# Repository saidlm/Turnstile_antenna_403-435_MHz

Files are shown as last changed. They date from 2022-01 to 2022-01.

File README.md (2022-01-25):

# Turnstile antenna
The antenna was primary designed for weather balloon tracker station based. It means my first dessign is for 403Mhz (400Mhz - 406Mhz). The solution is based on well know priciples which can be easily found on the Internet. The next one is planned for satellite receiver on 435 Mhz band.

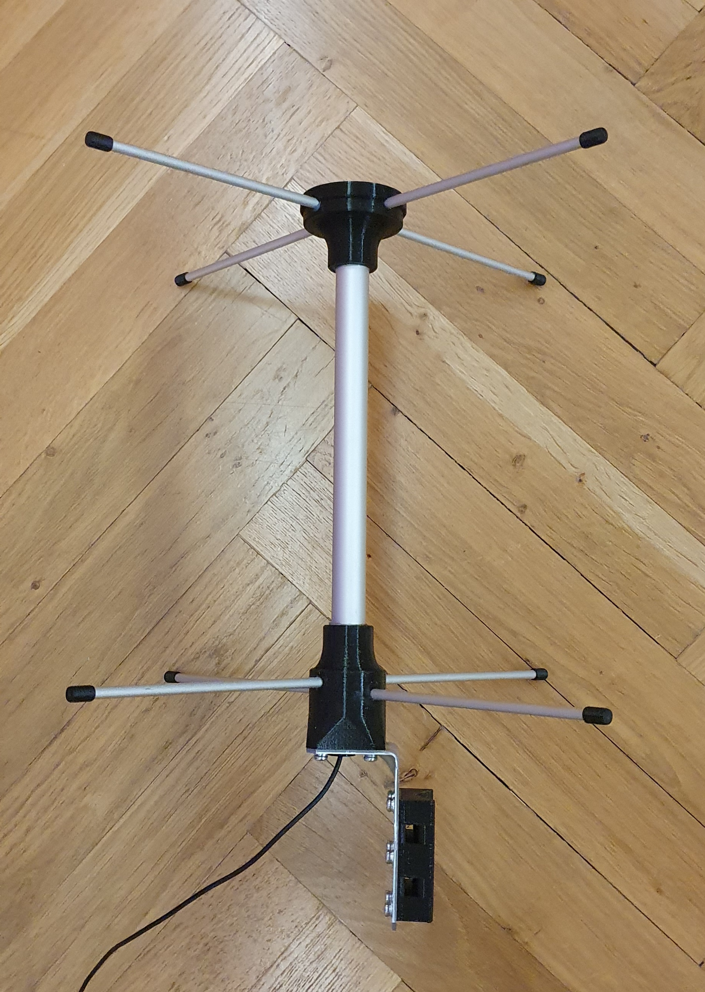
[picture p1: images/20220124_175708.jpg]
Turnstile Antenna


## Mechanical design
All platic parts have been printed from PET on Prusa MK2 3D printer. Four perimeters and 80% infill have been chousen. 
Measurements of ALU parts are summarized below. Dipole pipes are fixed with four screws M3x16mm. They are used for cables connection as well. Reflector pipes are fixed with one screw in the tube joint inside the bottom plastic part. To make whole antenna waterproof sillicone glue has been used.

## Turnstile antenna for 403Mhz

|Part|Description|
| :--- | :--- |
| **Dipole** |  4 pcs of ALU pipe 6mm x 164mm |
| **Reflector** |  2 pcs of ALU pipe 6mm x 354mm |
| **Pole** | 1 pc of ALU pipe 20mm x 262mm|

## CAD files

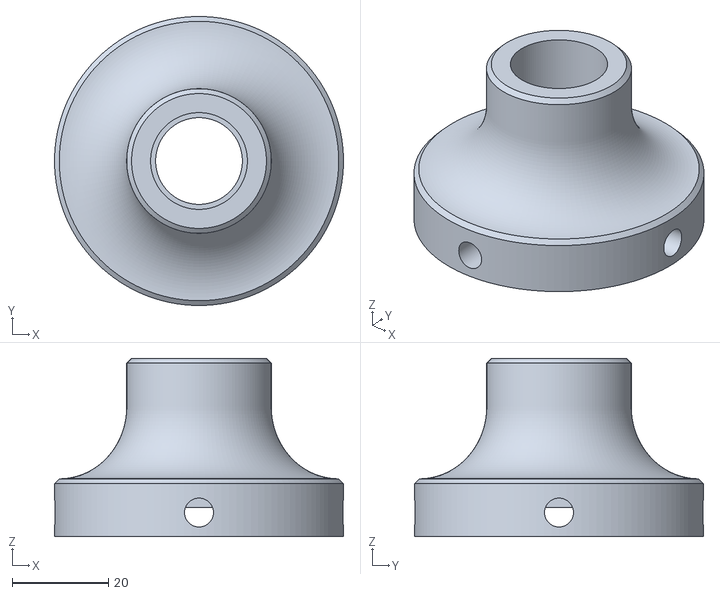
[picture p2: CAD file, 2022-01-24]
stl/top-0.1.stl
60.0 x 60.0 x 37.0

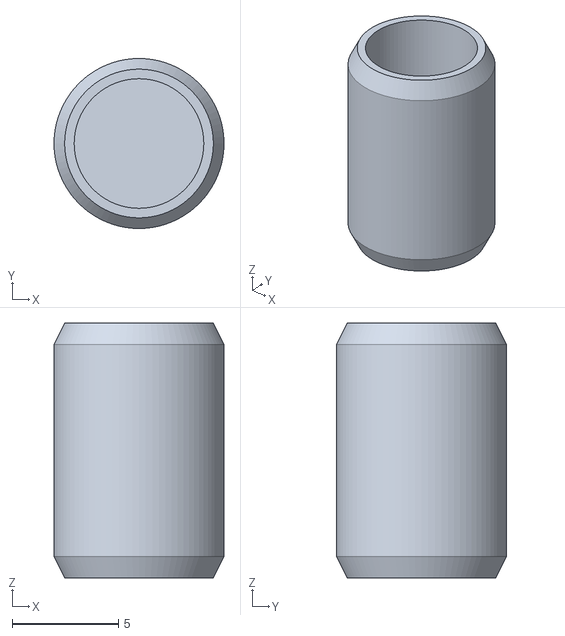
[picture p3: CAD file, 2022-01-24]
stl/end-cover-0.1.stl
8.00 x 8.00 x 12.0

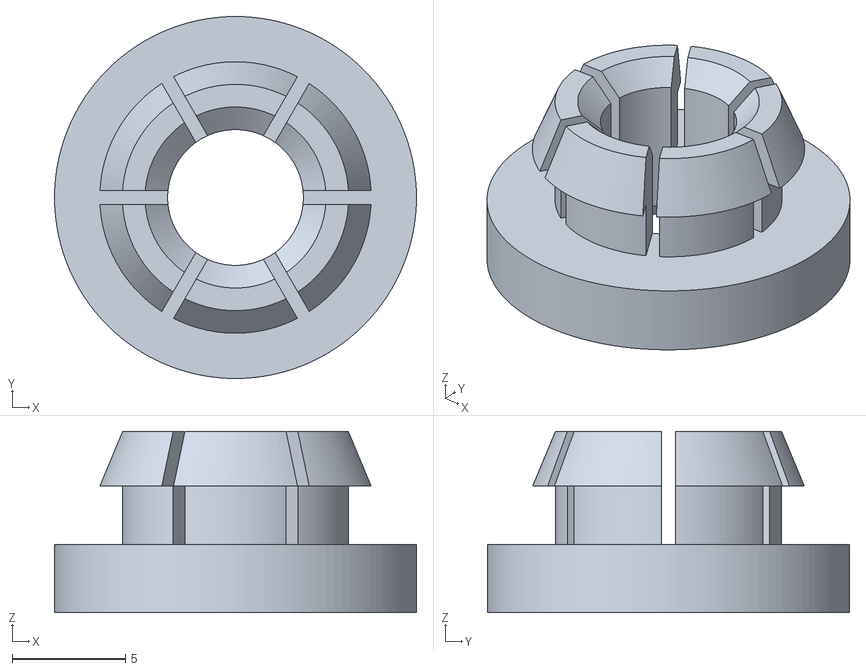
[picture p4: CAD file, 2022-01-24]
stl/cable-protection-0.1.stl
16.0 x 16.0 x 8.00

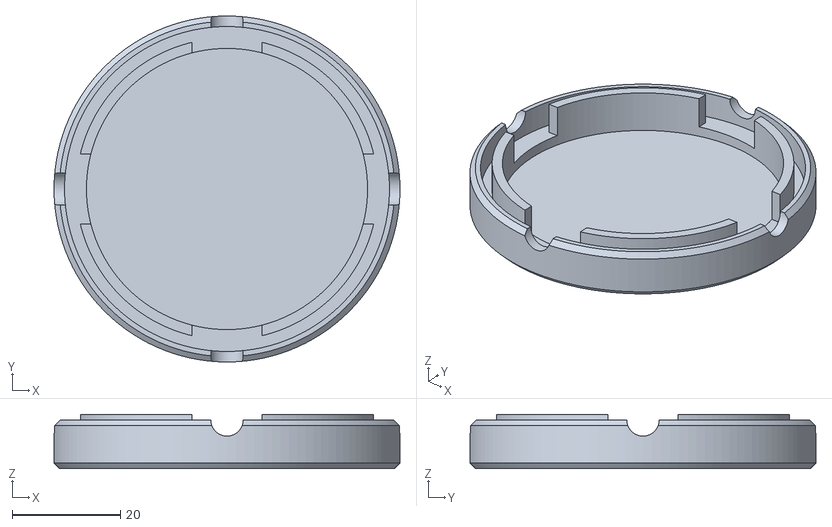
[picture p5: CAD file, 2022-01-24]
stl/top-cover-0.2.stl
64.0 x 64.0 x 10.0

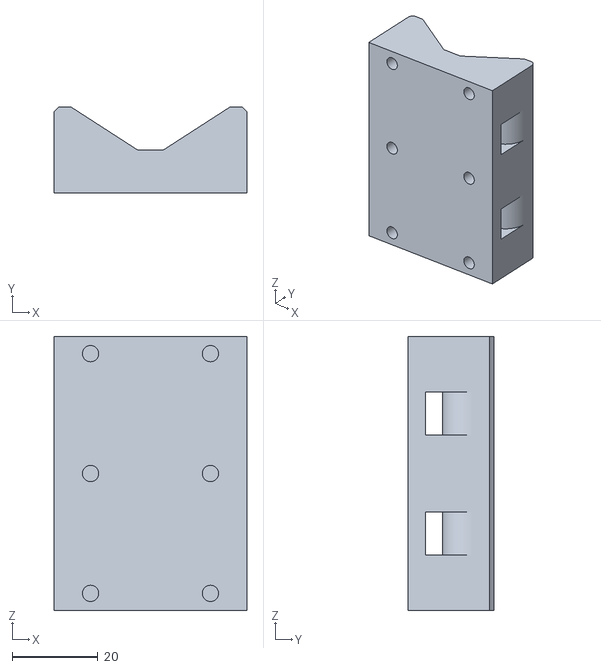
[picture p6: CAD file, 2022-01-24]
stl/holder-0.1.stl
45.0 x 20.0 x 64.0

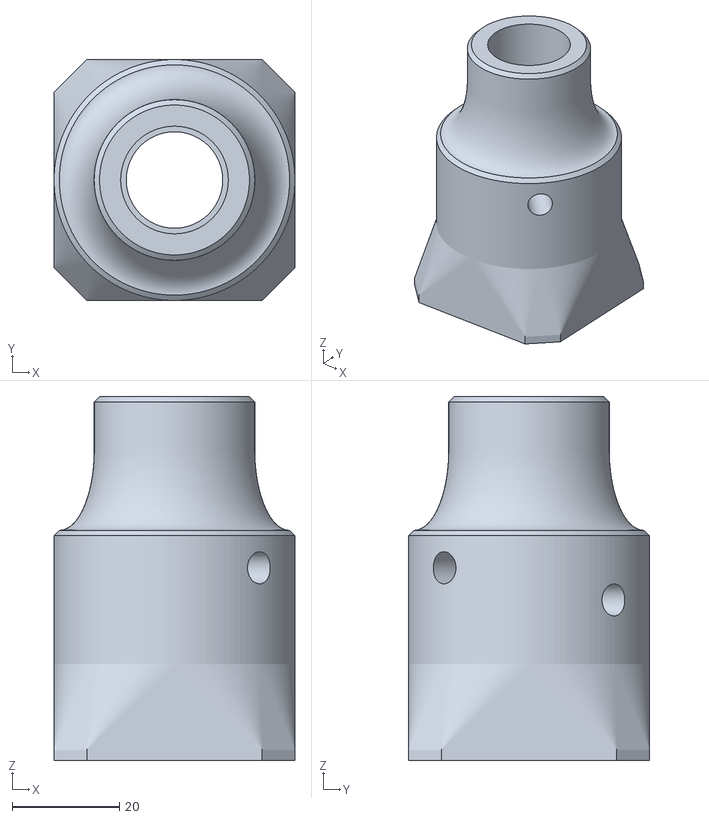
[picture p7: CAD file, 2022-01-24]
stl/bottom-0.2.stl
45.0 x 45.0 x 68.0

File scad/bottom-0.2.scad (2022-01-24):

$fn=120;
translate([0,0,25])difference() {
    union() {
        difference() {
            union() {
                cylinder(h=17, d=45);
                translate([0,0,17]) cylinder(h=1,d1=45,d2=43);
                cylinder(h=33, d=43);
                cylinder(h=42, d=30);
                translate([0,0,42]) cylinder(h=1,d1=30,d2=28);
            }
            translate([0,0,18])cylinder(h=25, d=20.1);
            cylinder(h=22, d=18);
            translate([0,0,33])
                rotate_extrude(convexity=10)
                translate([21.5, 0, 0])
                resize([13,30])circle(r=10);
        }  
    }
    translate([0,0,11])rotate([90,0,45])cylinder(h=60, d=6, center=true);
    translate([0,0,5])rotate([0,90,45])cylinder(h=60, d=6, center=true);
}

difference() {
    union() {
    cylinder(h=25, d=45);
    hull() {
        cylinder(h=18, d=45);
        translate([0,0,1])intersection() {
            cube([45,45,2], center=true);
            rotate([0,0,45])cube([55,55,2], center=true);
        }
    }
}
    cylinder(h=25, d1=25, d2=18);
    translate([14,14,0]) cylinder(h=15, d=3.7);
    translate([-14,14,0]) cylinder(h=15, d=3.7);
    translate([14,-14,0]) cylinder(h=15, d=3.7);
    translate([-14,-14,0]) cylinder(h=15, d=3.7);
}

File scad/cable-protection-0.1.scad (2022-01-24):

$fn=120;
difference() {
    union() {
        cylinder(h=3, d=16);
        cylinder(h=8, d=10);
        translate([0,0,5.6]) cylinder(h=2.4, d1=12, d2=10);
    }
    cylinder(h=1, d1=8, d2=6);
    cylinder(h=8, d=6);
    translate([0,0,7]) cylinder(h=1, d1=6, d2=8);
    translate([-6,-0.3,3]) cube([12,0.6,6]);
    rotate([0,0,60])translate([-6,-0.3,3]) cube([12,0.6,6]);
    rotate([0,0,120])translate([-6,-0.3,3]) cube([12,0.6,6]);
}

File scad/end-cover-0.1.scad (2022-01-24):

$fn=80;
difference(){
    union() {
        cylinder(h=1, d1=7, d2=8);
        translate([0,0,1])cylinder(h=10, d=8);
        translate([0,0,11])cylinder(h=1, d1=8, d2=7);
    }
    translate([0,0,2])cylinder(h=10, d=6.1);
}

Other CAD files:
scad/holder-0.1.scad
scad/top-0.1.scad
scad/top-cover-0.2.scad
